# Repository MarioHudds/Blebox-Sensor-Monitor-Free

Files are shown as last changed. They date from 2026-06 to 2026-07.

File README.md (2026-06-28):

# 🌡️ Monitor Sensorów Blebox (ESP32-C3) / Blebox Sensor Monitor

*(Scroll down for the English version)*

Projekt garażowy open-source pozwalający na ciągłe wyświetlanie danych z czujników ekosystemu Blebox (tempSensor, humiditySensor, multiSensor) na klasycznym ekranie LCD 16x2 lub 24x4.

Zamiast polegać na chmurze producenta, urządzenie wykorzystuje architekturę hybrydową Bleboxa – komunikuje się z czujnikami całkowicie lokalnie, w obrębie domowej sieci Wi-Fi lub przez bezpośredni punkt dostępowy (AP) sensora, używając otwartego API po protokole HTTP (mechanizm pollingu).

## 🚀 Funkcje

* **Lokalne działanie:** Brak opóźnień chmurowych, odporność na awarie internetu.
* **Auto-wykrywanie mDNS:** Nie musisz znać adresu IP swojego sensora. Monitor sam znajdzie go w sieci po przyjaznej nazwie (`.local`).
* **Captive Portal:** Łatwa konfiguracja z poziomu przeglądarki w telefonie po pierwszym uruchomieniu.
* **Wsparcie dla sieci chronionych:** Możliwość łączenia się z zabezpieczonymi sieciami AP (Access Point) udostępnianymi przez czujniki.
* **Niezawodność:** Wbudowane mechanizmy ponawiania połączenia i obsługi błędów sieci (np. brak migotania ekranu przy chwilowej utracie sygnału).

## 🛠️ Wymagania sprzętowe (Pinout)

Projekt został zoptymalizowany dla mikrokontrolerów z rodziny **ESP32-C3** (np. SuperMini).

* **Wyświetlacz LCD 16x2 lub 24x4 dla odpowiedniego kodu (I2C, adres 0x27):**
  * `SDA` -> GPIO 10
  * `SCL` -> GPIO 20
* **Przycisk fizyczny (do nawigacji i resetu):**
  * `PIN` -> GPIO 4 (zwiera do GND, używa wbudowanego pull-up)
* **Dioda RGB (wyłączana programowo, by nie raziła):**
  * `DIN` -> GPIO 8 (wbudowana w płytkę SuperMini)

## 💻 Środowisko programistyczne i instalacja

**Ważne:** Oprogramowanie zostało stworzone i przetestowane w środowisku **Arduino IDE w wersji 2.3.6**. Ze względu na dynamiczny rozwój rdzenia ESP32 dla Arduino, używanie nowszych wersji kompilatora może wymagać drobnych korekt w kodzie lub downgrade'u bibliotek.

### Krok 1: Przygotowanie Arduino IDE

1. Dodaj wsparcie dla płytek ESP32 w *Preferencjach* (Adres URL menedżera dodatkowych płytek).
2. W Menedżerze Płytek zainstaluj pakiet `esp32` (autor: Espressif Systems).
3. Wybierz płytkę z menu: **ESP32C3 Dev Module** (lub odpowiednik dla Twojej płytki).

### Krok 2: Wymagane biblioteki

Otwórz Menedżera Bibliotek w Arduino IDE i upewnij się, że masz zainstalowane poniższe pozycje:

* `ArduinoJson` (autor: Benoit Blanchon) – do parsowania odpowiedzi HTTP
* `LiquidCrystal I2C` (autor: Frank de Brabander) – do obsługi ekranu
* `Adafruit NeoPixel` (autor: Adafruit) – do obsługi wbudowanej diody LED
* *Biblioteki wbudowane w rdzeń ESP32 (nie musisz ich doinstalowywać):* `WiFi`, `HTTPClient`, `Wire`, `EEPROM`, `DNSServer`, `WebServer`, `ESPmDNS`.

### Krok 3: Wgrywanie i bezpieczeństwo

Otwórz plik `.ino` i wgraj go na płytkę. **Uwaga dotycząca bezpieczeństwa:** Twoje hasła do Wi-Fi zapisywane są w wydzielonej partycji pamięci (EEPROM/Flash). Przed przekazaniem gotowego urządzenia komuś obcemu, zawsze wykonaj twardy reset (przytrzymanie przycisku przez >3 sekundy), aby wymazać swoje poufne dane dostępowe.

## ⚙️ Pierwsze uruchomienie

1. Po włączeniu na ekranie pojawi się informacja o trybie pracy.
2. Jeśli urządzenie nie jest skonfigurowane, uruchomi własną sieć Wi-Fi o nazwie **Monitor_TSHS**.
3. Połącz się z tą siecią ze swojego telefonu/komputera. Zostaniesz automatycznie przekierowany na stronę konfiguracyjną (jeśli nie, wpisz w przeglądarce `192.168.4.1`).
4. Wybierz z listy swoją sieć domową Wi-Fi i podaj hasło. Zapisz i poczekaj na restart urządzenia.

## 📄 Licencja

Projekt udostępniany na licencji **MIT**. Możesz modyfikować kod, używać go w projektach komercyjnych i dowolnie rozpowszechniać. Twórcy nie ponoszą odpowiedzialności za błędy wynikające z działania oprogramowania.

---

# 🇬🇧 English Version

An open-source, garage-developed standalone display for the Blebox ecosystem sensors (tempSensor, humiditySensor, multiSensor) using a classic 16x2 LCD.

Instead of relying on the manufacturer's cloud, this device uses Blebox's hybrid architecture – communicating with sensors entirely locally within your home Wi-Fi network or directly via the sensor's Access Point (AP). It fetches data using the open HTTP API (polling mechanism).

## 🚀 Features

* **Local Operation:** No cloud latency, immune to internet outages.
* **mDNS Auto-Discovery:** No need to hardcode IP addresses. The monitor finds the sensor via its `.local` hostname.
* **Captive Portal:** Easy mobile browser configuration on first boot.
* **Protected Network Support:** Ability to connect to secure APs provided by sensors.
* **Reliability:** Built-in reconnection mechanisms and network error handling (prevents screen flickering during temporary signal loss).

## 🛠️ Hardware Requirements (Pinout)

The project is optimized for the **ESP32-C3** family (e.g., SuperMini board).

* **16x2 LCD Display (I2C, address 0x27):**
  * `SDA` -> GPIO 10
  * `SCL` -> GPIO 20
* **Physical Button (navigation & reset):**
  * `PIN` -> GPIO 4 (shorts to GND, uses internal pull-up)
* **RGB LED (disabled via software):**
  * `DIN` -> GPIO 8 (built into the SuperMini board)

## 💻 Development Environment & Installation

**Important:** This software was developed and tested using **Arduino IDE version 2.3.6**. Due to the rapid development of the ESP32 Arduino core, compiling on newer versions might require minor code adjustments or library downgrades.

### Step 1: Arduino IDE Setup

1. Add ESP32 board support in *Preferences* (Additional Boards Manager URLs).
2. Install the `esp32` package by Espressif Systems via the Boards Manager.
3. Select your board: **ESP32C3 Dev Module** (or similar).

### Step 2: Required Libraries

Open the Library Manager and install:

* `ArduinoJson` (by Benoit Blanchon) – for parsing HTTP responses
* `LiquidCrystal I2C` (by Frank de Brabander) – for the display
* `Adafruit NeoPixel` (by Adafruit) – for onboard LED management
* *Core libraries (included with ESP32 core, no installation needed):* `WiFi`, `HTTPClient`, `Wire`, `EEPROM`, `DNSServer`, `WebServer`, `ESPmDNS`.

### Step 3: Flashing & Security Practices

Open the `.ino` file and flash it to your board. **Security Note:** Your Wi-Fi credentials are saved in the device's non-volatile memory (EEPROM/Flash). Before handing the physical device to someone else, always perform a hard reset (hold the button for >3 seconds) to erase your access data.

## ⚙️ Initial Setup

1. Upon power-up, the screen will display the current connection mode.
2. If unconfigured, it will broadcast a Wi-Fi network named **Monitor_TSHS**.
3. Connect to this network using your smartphone. You should be automatically redirected to the setup portal (if not, navigate to `192.168.4.1`).
4. Select your home Wi-Fi network, enter the password, save, and wait for the device to reboot.

## 📄 License

This project is licensed under the **MIT License**. You are free to modify, distribute, and use it in commercial applications. The authors are not liable for any issues arising from the use of this software.

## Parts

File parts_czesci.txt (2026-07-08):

## 🛒 Lista części (BOM) i przykładowe linki

Do złożenia Monitora w wersji 16x2 lub 20x4 i zamontowania go w obudowie 3D potrzebujesz poniższych części. Podane linki mają charakter wyłącznie poglądowy (mogą z czasem wygasnąć) – podczas zakupów kieruj się przede wszystkim nazwami i parametrami.
Części można kupić znacznie taniej niż są w poniższych linkach. Trzeba szukać ich na 'Bundle Deals' w Ali.

https://pl.aliexpress.com/item/1005006520514745.html

https://pl.aliexpress.com/item/1005009681060148.html

https://pl.aliexpress.com/item/1005009897797706.html

https://pl.aliexpress.com/item/1005008989080790.html

https://pl.aliexpress.com/item/1005006478143379.html

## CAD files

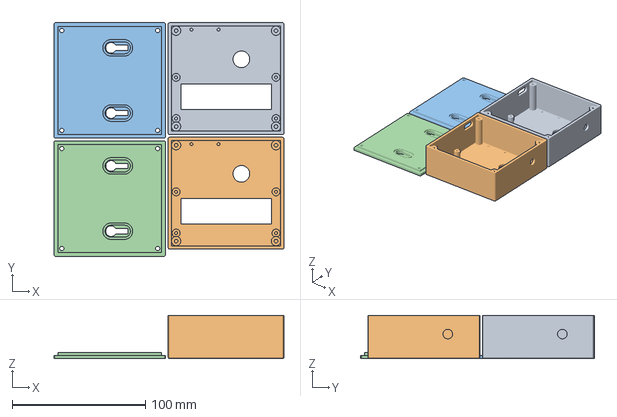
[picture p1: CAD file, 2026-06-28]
Enclosure_16x2_base_Lid_petgMatte_prod.3mf
172.7 x 175.4 x 32.5 mm
1602_enclosure_10072025_base_prod.stl x 2
1602_enclosure_base_Lid_84_prod.stl_2 x 2

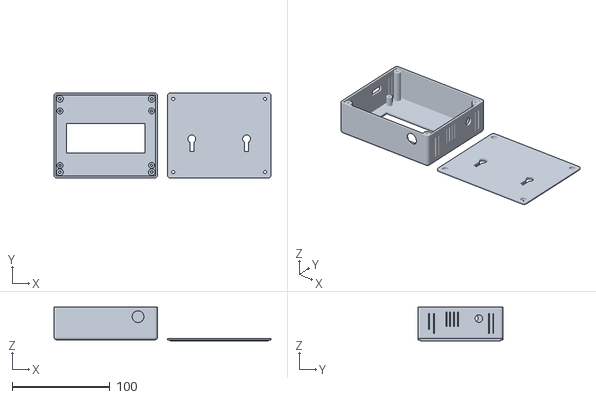
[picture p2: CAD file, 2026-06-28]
Enclosure_20x4_small_thinner_with_antenna_ventsGitHub.stl
222.0 x 87.0 x 34.5

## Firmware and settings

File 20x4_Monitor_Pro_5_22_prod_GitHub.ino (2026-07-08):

// ===================================================================================
//
//      ESP32-C3 PRO Project - Version 5.22 PL (Multi-Sensor FINAL)
//
// ===================================================================================
//
//v5.22 Fixed reconnection
//v5.21 Wind Unit in Carousel Mode & Unit is Not Saved
//v5.20 the password visibility fixed
//
// v5.17 Changelog:
//   - OPTIMIZE: Refactored display functions to use C-style strings (char arrays) 
//               instead of String objects to reduce heap fragmentation.
//   - OPTIMIZE: Modified HTTP fetching to parse JSON directly from the network stream,
//               avoiding large intermediate String allocations.
//
// v5.16 Changelog:
//   - FEATURE: Added manual/infinite carousel mode. Set interval to "Reczny" (Manual).
//
// v5.15 Changelog:
//   - REFACTOR: Created printHeaderLine() helper to centralize header/counter display.
//   - REFACTOR: Created handleFactoryReset() helper to centralize reset logic.
//
// v5.13 User Changes:
//   - FIX: Corrected carousel counter display (removed brackets, fixed positioning).
//   - FIX: Added reset functionality to the AP scanning menu.
//
// ===================================================================================
//
// -- Hardware & Pinout --
// Board: ESP32-C3 SuperMini / SuperMini Plus
// LCD Display (I2C):
//   - SDA: GPIO 10
//   - SCL: GPIO 20
// Button:
//   - PIN: GPIO 4
// Onboard RGB LED (WS2812):
//   - DIN: GPIO 8
//
// ===================================================================================

// --- Core Libraries ---
#include <WiFi.h>
#include <HTTPClient.h>
#include <Wire.h>
#include <ArduinoJson.h>
#include <LiquidCrystal_I2C.h>
#include <EEPROM.h>

// --- New Libraries for WiFi Mode & LED ---
#include <DNSServer.h>
#include <WebServer.h>
#include <ESPmDNS.h>
#include <Adafruit_NeoPixel.h>

// --- Configuration ---
#define NEOPIXEL_PIN 8
#define NUM_PIXELS   1
Adafruit_NeoPixel strip(NUM_PIXELS, NEOPIXEL_PIN, NEO_GRB + NEO_KHZ800);

// --- User Configuration Flag ---
#define WIND_UNIT_MODE 0
#define MAX_SENSORS 5    // Maximum number of sensors to support

const int I2C_ADDR = 0x27;
const int SDA_PIN = 10;
const int SCL_PIN = 20;
const int LCD_COLS = 20;
const int LCD_ROWS = 4;
LiquidCrystal_I2C lcd(I2C_ADDR, LCD_COLS, LCD_ROWS);

const int BUTTON_PIN = 4;
const char* CAPTIVE_PORTAL_SSID = "Monitor_PRO";
const char* MONITOR_HOSTNAME = "monitor";
WebServer webServer(80);
DNSServer dnsServer;

enum SensorType { SENSOR_UNKNOWN, SENSOR_TEMP, SENSOR_HUMIDITY, SENSOR_WIND, SENSOR_MULTI_TEMP };
enum WindUnit { UNIT_MS, UNIT_KMH, UNIT_MPH, UNIT_KNOTS };
enum ConnectionMode { MODE_UNSET = 0, MODE_AP = 1, MODE_WIFI = 2, MODE_AP_SECURE_SETUP = 3 };

// --- EEPROM Configuration (v5.00) ---
struct SensorInfo {
  char mDNSSensorName[65];         // e.g., "czujnik-garaz.local". Empty if manual IP.
  char mDNSSensorFriendlyName[33]; // e.g., "Czujnik Garaz"
  char sensorIp[16];               // Can be a manual IP or a cached IP from mDNS.
};

struct Settings {
  int connectionMode;
  char wifiSSID[33];
  char wifiPassword[65];

  // --- Single AP Mode Settings ---
  char apModeSsid[33];
  bool connectToProtectedAP;
  char protectedApSsid[33];
  char protectedApPassword[65];

  // --- Multi-sensor WiFi Mode Settings ---
  int sensorCount;
  SensorInfo selectedSensors[MAX_SENSORS];
  int carouselInterval; // in seconds

  WindUnit windUnit; // Add a variable to store the preferred wind unit
};

const int EEPROM_ADDR = 0;
const int EEPROM_SIZE = sizeof(Settings) + 1;
Settings settings;




bool firstWifiRun = true;
int buttonState = HIGH;
int lastButtonState = HIGH;
unsigned long lastDebounceTime = 0;
unsigned long buttonPressStartTime = 0;
WindUnit currentWindUnit = UNIT_MS;

const int MAX_FOUND_APS = 10;
String foundAP_SSIDs[MAX_FOUND_APS];
String foundAP_DisplayNames[MAX_FOUND_APS];
int foundAPCount = 0;
const int MAX_MDNS_SERVICES = 20;
String foundMDNS_Names[MAX_MDNS_SERVICES];
String foundMDNS_Hostnames[MAX_MDNS_SERVICES];
int foundMDNSCount = 0;
String selectedSensorHostname = ""; // Legacy, will be phased out.
String baseApiUrl = "";
SensorType connectedSensorApiType = SENSOR_UNKNOWN;
unsigned long lastDataFetchTime = 0; // Re-purposed for carousel timer

const char* DATA_ENDPOINT_PATH = "/state/extended";
const char* INFO_ENDPOINT_PATH = "/info";

int currentSensorIndex = 0;
IPAddress sensorIPs[MAX_SENSORS]; // Session cache for resolved IP addresses

const char* TEMP_AP_PREFIX_1 = "tempSensor-";
const char* TEMP_AP_PREFIX_2 = "tempSensor_v2-";
const char* TEMP_AC_AP_PREFIX = "tempSensorAC-";
const char* TEMP_AC_V2_AP_PREFIX = "tempSensorAC_v2-";
const char* TEMP_PRO_AP_PREFIX = "tempSensorPRO-";
const char* TEMP_PRO_UNDERSCORE_AP_PREFIX = "tempSensor_PRO-";
const char* TEMP_PRO_V2_AP_PREFIX = "tempSensor_PRO_v2-";
const char* TEMP_DIN_AP_PREFIX = "tempSensor_DIN-";
const char* HUMIDITY_AP_PREFIX = "humiditySensor-";
const char* HUMIDITY_AP_PREFIX_V2 = "humiditySensor_v2-"; // NEW (v5.12)
const char* WIND_AP_PREFIX = "windSensor_PRO-";
const char* WIND_RAIN_AP_PREFIX = "windRainSensor-";

const int NO_PRESS = 0;
const int SHORT_PRESS_DETECTED = 1;
const int LONG_PRESS_DETECTED = 2;
const int VERY_LONG_PRESS_DETECTED = 3;
const unsigned long DEBOUNCE_DELAY = 50;
const unsigned long SHORT_PRESS_MAX_DURATION = 1000;
const unsigned long LONG_PRESS_MIN_DURATION = 3000;
const unsigned long VERY_LONG_PRESS_MIN_DURATION = 7000;

byte degreeSymbol[8] = { 0b00110, 0b01001, 0b01001, 0b00110, 0b00000, 0b00000, 0b00000, 0b00000 };
byte upArrow[8] = { 0B00100, 0B01110, 0B11111, 0B00100, 0B00100, 0B00000, 0B00000, 0B00000 };
byte downArrow[8] = { 0B00000, 0B00000, 0B00100, 0B00100, 0B11111, 0B01110, 0B00100, 0B00000 };
byte rssiGraphic1[8] = { 0b00000, 0b00000, 0b00000, 0b00000, 0b00000, 0b00000, 0b10000, 0b10000 };
byte rssiGraphic2[8] = { 0b00000, 0b00000, 0b00000, 0b00000, 0b01000, 0b01000, 0b11000, 0b11000 };
byte rssiGraphic3[8] = { 0b00000, 0b00000, 0b00100, 0b00100, 0b01100, 0b01100, 0b11100, 0b11100 };
byte rssiGraphic4[8] = { 0b00010, 0b00010, 0b00110, 0b00110, 0b01110, 0b01110, 0b11110, 0b11110 };
byte waterDrop[8] = { 0b00100, 0b00100, 0b01010, 0b01010, 0b11001, 0b11001, 0b11101, 0b01110 };
const byte DEGREE_CHAR_INDEX = 0, UP_ARROW_CHAR_INDEX = 1, DOWN_ARROW_CHAR_INDEX = 2, RSSI_GRAPHIC_1_INDEX = 3, RSSI_GRAPHIC_2_INDEX = 4, RSSI_GRAPHIC_3_INDEX = 5, RSSI_GRAPHIC_4_INDEX = 6, WATER_DROP_CHAR_INDEX = 7;

struct SensorReading {
  int tempProbeCount;
  float temperatures[4];
  int tempTrends[4];
  String probeNames[4];
  bool tempSuccess;
  float humidity;
  int humidityTrend;
  bool humiditySuccess;
  float windSpeed;
  float windAvg;
  float windMax;
  bool windSuccess;
};

struct DeviceInfo {
  String deviceName;
  String apiType;
  String product;
  bool success;
};

// --- State Tracking Variables ---
DeviceInfo lastGoodDeviceInfo;
SensorReading lastGoodSensorData;
long lastGoodRSSI = -100;
bool hasDataToDisplay = false;
String lastDisplayedName = "";
// --- REFACTOR START: Replaced String arrays with char arrays ---
#define MAX_VALUE_LEN 11        // Max length for a displayed value string (e.g., "-123.45\0")
#define MAX_PROBE_NAME_LEN 11   // Max length for a probe name (display truncates to 10)
char lastDisplayedValues[4][MAX_VALUE_LEN] = {"", "", "", ""};
char lastDisplayedProbeNames[4][MAX_PROBE_NAME_LEN] = {"", "", "", ""};
// --- REFACTOR END ---
int lastDisplayedTrends[4] = {-1, -1, -1, -1};
long lastDisplayedRSSI = -200;
SensorType lastDisplayedType = SENSOR_UNKNOWN;
WindUnit lastWindUnit = UNIT_MS;
int consecutiveFetchFailures = 0;
const int MAX_CONSECUTIVE_FETCH_FAILURES = 3;
int lastProbeCount = -1;

// --- Function Declarations ---
void loadSettings(); void saveSettings(); void eraseSettings(); void setup(); void loop(); int checkButton();
void handleDataFetching();
ConnectionMode selectConnectionMode();
void startCaptivePortal(); void handleWifiConfigRoot(); void handleWifiConfigSave();
void handleNotFound();
void handleSettingsMenu();
bool discoverAndSelectMDNS_Sensor();
bool scanAndSelectAP(); bool connectToAP(const String& ssid, const char* password = nullptr);
DeviceInfo fetchDeviceInfo(const String& endpoint); SensorReading fetchSensorData(const String& endpoint, SensorType type);
void displayTemp(const DeviceInfo& info, const SensorReading& data, long rssi);
void displayHumidity(const DeviceInfo& info, const SensorReading& data, long rssi);
void displayWind(const DeviceInfo& info, const SensorReading& data, long rssi);
void displayMultiTemp(const DeviceInfo& info, const SensorReading& data, long rssi);
// --- NEW HELPER FUNCTIONS ---
void handleFactoryReset();
void printHeaderLine(const String& deviceName);

// ===================================================================================
//                                  SETUP
// ===================================================================================
void setup() {
  // Serial.begin(115200);
  pinMode(BUTTON_PIN, INPUT_PULLUP);

  strip.begin();
  strip.clear();
  strip.setPixelColor(0, strip.Color(0, 0, 0));
  strip.show();

  delay(500);

  Wire.begin(SDA_PIN, SCL_PIN);
  lcd.init();
  lcd.backlight();
  lcd.clear();
  delay(50);
  lcd.createChar(DEGREE_CHAR_INDEX, degreeSymbol);
  lcd.createChar(UP_ARROW_CHAR_INDEX, upArrow);
  lcd.createChar(DOWN_ARROW_CHAR_INDEX, downArrow);
  lcd.createChar(RSSI_GRAPHIC_1_INDEX, rssiGraphic1);
  lcd.createChar(RSSI_GRAPHIC_2_INDEX, rssiGraphic2);
  lcd.createChar(RSSI_GRAPHIC_3_INDEX, rssiGraphic3);
  lcd.createChar(RSSI_GRAPHIC_4_INDEX, rssiGraphic4);
  lcd.createChar(WATER_DROP_CHAR_INDEX, waterDrop);

  EEPROM.begin(EEPROM_SIZE);
  loadSettings();

  bool setupOk = false;
  if (settings.connectToProtectedAP) {
      lcd.clear();
      lcd.print("Laczenie z...");
      lcd.setCursor(0,1);
      lcd.print(settings.protectedApSsid);
      while(!connectToAP(settings.protectedApSsid, settings.protectedApPassword)) {
          lcd.clear();
          lcd.print("Szukam AP...");
          lcd.setCursor(0,1);
          lcd.print(String(settings.protectedApSsid).substring(0,20));
          delay(2000);
      }
      settings.connectionMode = MODE_AP;
      setupOk = true;
  } else {
    if (settings.connectionMode == MODE_UNSET) {
      settings.connectionMode = selectConnectionMode();
      if (settings.connectionMode == MODE_AP_SECURE_SETUP || (settings.connectionMode == MODE_WIFI && strlen(settings.wifiSSID) == 0)) {
          startCaptivePortal();
      }
      saveSettings();
    }
  }

  if (settings.connectionMode == MODE_AP) {
    if (strlen(settings.apModeSsid) > 0) {
        lcd.clear();
        lcd.print("Laczenie z...");
        lcd.setCursor(0,1);
        lcd.print(settings.apModeSsid);
        while(!connectToAP(settings.apModeSsid)) {
            lcd.clear();
            lcd.print("Szukam AP...");
            lcd.setCursor(0,1);
            lcd.print(String(settings.apModeSsid).substring(0,20));
            delay(2000);
        }
        setupOk = true;
    } else if (!settings.connectToProtectedAP) {
        setupOk = scanAndSelectAP();
    } else {
        setupOk = true;
    }

  } else if (settings.connectionMode == MODE_WIFI) {
    if (strlen(settings.wifiSSID) == 0) {
      startCaptivePortal();
    }

    lcd.clear();
    lcd.print("Tryb WiFi");
    delay(1500);
    lcd.clear();
    lcd.print("Laczenie z WiFi");
    lcd.setCursor(0, 1);
    lcd.print(settings.wifiSSID);

    WiFi.begin(settings.wifiSSID, settings.wifiPassword);
    unsigned long startTime = millis();
    while (WiFi.status() != WL_CONNECTED) {
      int press = checkButton();
      if (press == VERY_LONG_PRESS_DETECTED) {
        // REPLACED WITH HELPER
        handleFactoryReset();
      }

      delay(250);
      lcd.print(".");
      // --- BUGFIX START: Do not erase settings on connection timeout ---
      // If 20 seconds pass and we're not connected, show an error and break
      // the loop instead of erasing the configuration. The main loop will
      // handle reconnection attempts.
      if (millis() - startTime > 20000) {
        lcd.clear();
        lcd.print("Blad polaczenia");
        lcd.setCursor(0, 1);
        lcd.print("Sprawdz ruter/AP");
        lcd.setCursor(0, 2);
        lcd.print("Sprobuje ponownie...");
        delay(4000);
        // eraseSettings(); // OLD DESTRUCTIVE BEHAVIOR - REMOVED
        // ESP.restart();   // OLD DESTRUCTIVE BEHAVIOR - REMOVED
        break; // Exit the connection loop and proceed to the main program
      }
      // --- BUGFIX END ---
    }

      // Only attempt mDNS setup or sensor discovery if we successfully connected.
    if (WiFi.status() == WL_CONNECTED) {
        if (!MDNS.begin(MONITOR_HOSTNAME)) {
            lcd.clear();
            lcd.print("Blad mDNS");
            delay(3000);
            // We don't restart, just note the error.
        }

        if (settings.sensorCount == 0) {
          setupOk = discoverAndSelectMDNS_Sensor();
        } else {
          setupOk = true;
        }
    } else {
        // If WiFi failed to connect, we still consider setup "ok" to allow
        // the main loop's reconnection logic to take over.
        setupOk = true;
    }
  }

  if (!setupOk) {
    lcd.clear();
    lcd.print("Blad konfiguracji");
    lcd.setCursor(0, 1);
    lcd.print("Restartuje...");
    delay(3000);
    eraseSettings();
    ESP.restart();
  }

  for(int i = 0; i < settings.sensorCount; i++) {
    sensorIPs[i].fromString(settings.selectedSensors[i].sensorIp);
  }

  lcd.clear();
  lcd.print("Gotowe");
  lastDataFetchTime = millis();
  delay(1000);
  handleDataFetching();
}


// ===================================================================================
//                                  MAIN LOOP
// ===================================================================================

void loop() {
  int press = checkButton();

  if (press == VERY_LONG_PRESS_DETECTED) {
    handleFactoryReset();
  } else if (press == LONG_PRESS_DETECTED) {
      if(settings.connectionMode == MODE_WIFI && settings.sensorCount > 1) {
        handleSettingsMenu();
        lastDataFetchTime = millis();

        lastDisplayedName = "";
        connectedSensorApiType = SENSOR_UNKNOWN;

        handleDataFetching();
      }
  } else if (press == SHORT_PRESS_DETECTED) {
    bool carouselAdvanced = false;
    if (settings.connectionMode == MODE_WIFI && settings.sensorCount > 1) {
        currentSensorIndex = (currentSensorIndex + 1) % settings.sensorCount;
        lastDataFetchTime = millis();

        lastDisplayedName = "";
        connectedSensorApiType = SENSOR_UNKNOWN;

        handleDataFetching();
        carouselAdvanced = true;
    }

    if (!carouselAdvanced && connectedSensorApiType == SENSOR_WIND) {
      if (WIND_UNIT_MODE == 0) {
          currentWindUnit = (currentWindUnit == UNIT_MS) ? UNIT_KMH : UNIT_MS;
      } else {
          currentWindUnit = (WindUnit)((currentWindUnit + 1) % 4);
      }

      // --- NEW: Persist the user's selection to EEPROM ---
      settings.windUnit = currentWindUnit;
      saveSettings();
      // --- END NEW ---

      lastDisplayedName = "";
      if(hasDataToDisplay) displayWind(lastGoodDeviceInfo, lastGoodSensorData, lastGoodRSSI);
    }
  }

  // --- BUGFIX START: Corrected data fetching logic for manual carousel mode ---

  // Case 1: Automatic Carousel is active.
  // This block handles both advancing the sensor AND fetching data on a user-defined timer.
  if (settings.connectionMode == MODE_WIFI && settings.sensorCount > 1 && settings.carouselInterval > 0) {
    if (millis() - lastDataFetchTime >= ((unsigned long)settings.carouselInterval * 1000)) {
        currentSensorIndex = (currentSensorIndex + 1) % settings.sensorCount;
        lastDataFetchTime = millis();

        lastDisplayedName = "";
        connectedSensorApiType = SENSOR_UNKNOWN;

        handleDataFetching();
    }
  }
  // Case 2: All other modes (AP, single sensor, or MANUAL carousel).
  // This block handles fetching data for the CURRENT sensor on a fixed 3-second timer.
  else if (settings.connectionMode == MODE_AP || (settings.connectionMode == MODE_WIFI && settings.sensorCount >= 1)) {
    if (millis() - lastDataFetchTime >= 3000) {
      lastDataFetchTime = millis();
      handleDataFetching();
    }
  }
  // --- BUGFIX END ---
}

// ===================================================================================
//                        NETWORK & DATA HANDLING FUNCTION
// ===================================================================================
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

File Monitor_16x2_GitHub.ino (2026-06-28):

// ===================================================================================
//
//      ESP32-C3 TSHS Project - Version 3.44 PL (Upgraded)
//
// ===================================================================================
//
// v3.44 Changelog:
//   - FIX (Protected AP Mode): The monitor no longer resets if the saved protected
//     sensor AP is unavailable on startup. It now uses the same persistent
//     reconnection logic as the standard AP mode.
//
// v3.43 Changelog:
//   - FIX (AP Mode): The monitor no longer resets its settings if the saved sensor
//     AP is unavailable on startup. It will now persistently try to reconnect
//     until successful, while still allowing for a manual reset via long press.
//
// v3.42 Changelog:
//   - FIX: Implemented a visual indicator for sensor connection loss.
//   - UX: When the sensor is disconnected, the monitor now displays "Utracono sygnal"
//     (Signal lost) instead of showing stale data, while continuing to attempt
//     reconnection in the background.
//
// ===================================================================================
//
// -- Hardware & Pinout --
// Board: ESP32-C3 SuperMini / SuperMini Plus
// LCD Display (I2C): 16x2
//   - SDA: GPIO 10
//   - SCL: GPIO 20
// Button:
//   - PIN: GPIO 4
// Onboard RGB LED (WS2812):
//   - DIN: GPIO 8
//
// ===================================================================================


// --- Core Libraries ---
// [EDUKACJA]: Podstawowe biblioteki do obsługi sieci, zapytań HTTP i interfejsów sprzętowych.
#include <WiFi.h>
#include <HTTPClient.h>
#include <Wire.h>               // Obsługa magistrali I2C (dla wyświetlacza)
#include <ArduinoJson.h>        // Parsowanie odpowiedzi z sensorów Blebox (które zwracają dane w formacie JSON)
#include <LiquidCrystal_I2C.h>  // Sterowanie ekranem LCD
#include <EEPROM.h>             // Zapisywanie ustawień w pamięci nieulotnej (flash)

// --- New Libraries for WiFi Mode & LED ---
// [EDUKACJA]: Biblioteki do zaawansowanych funkcji sieciowych.
#include <DNSServer.h>          // Przechwytywanie zapytań DNS (niezbędne do działania "Captive Portal")
#include <WebServer.h>          // Wbudowany miniserwer WWW do konfiguracji przez przeglądarkę
#include <ESPmDNS.h>            // Multicast DNS: pozwala szukać urządzeń po nazwach (np. sensor.local) bez znajomości ich IP
#include <Adafruit_NeoPixel.h>

// --- Configuration ---
#define NEOPIXEL_PIN 8
#define NUM_PIXELS   1
Adafruit_NeoPixel strip(NUM_PIXELS, NEOPIXEL_PIN, NEO_GRB + NEO_KHZ800);

const int I2C_ADDR = 0x27; // [EDUKACJA]: Najpopularniejszy adres I2C dla tanich modułów LCD. Jeśli masz krzaczki na ekranie, sprawdź 0x3F.
const int SDA_PIN = 10;
const int SCL_PIN = 20;
LiquidCrystal_I2C lcd(I2C_ADDR, 16, 2);

const int BUTTON_PIN = 4;
const char* CAPTIVE_PORTAL_SSID = "Monitor_TSHS";
const char* MONITOR_HOSTNAME = "monitor";
WebServer webServer(80); // [EDUKACJA]: Serwer nasłuchuje na standardowym porcie HTTP (80)
DNSServer dnsServer;

// --- EEPROM Configuration ---
// [EDUKACJA][BEZPIECZEŃSTWO]: Ta struktura przechowuje dane konfiguracyjne. 
// Uwaga dla zaawansowanych: hasła (wifiPassword) są tutaj zapisywane jawnym tekstem. 
// Przy fizycznym dostępie do układu ESP32 można je odczytać. W projektach domowych to akceptowalne ryzyko.
struct Settings {
  int connectionMode;
  char wifiSSID[33];
  char wifiPassword[65];
  char mDNSSensorName[65];
  char mDNSSensorFriendlyName[33];
  char apModeSsid[33];

// New fields for protected AP mode
  bool connectToProtectedAP;
  char protectedApSsid[33];
  char protectedApPassword[65];
};
const int EEPROM_ADDR = 0;

const int EEPROM_SIZE = sizeof(Settings) + 1; // [EDUKACJA]: Rezerwujemy dokładnie tyle bajtów, ile waży nasza struktura
Settings settings;

// --- Enums, Globals, Constants, Structs... ---
enum ConnectionMode { MODE_UNSET = 0, MODE_AP = 1, MODE_WIFI = 2, MODE_AP_SECURE_SETUP = 3 };

bool firstWifiRun = true;
int buttonState = HIGH;
int lastButtonState = HIGH;
unsigned long lastDebounceTime = 0;

unsigned long buttonPressStartTime = 0;
bool longPressTriggered = false;
const int MAX_FOUND_APS = 10;
String foundAP_SSIDs[MAX_FOUND_APS];
String foundAP_DisplayNames[MAX_FOUND_APS];

int foundAPCount = 0;
const int MAX_MDNS_SERVICES = 10;
String foundMDNS_Names[MAX_MDNS_SERVICES];
String foundMDNS_Hostnames[MAX_MDNS_SERVICES];
int foundMDNSCount = 0;

String selectedSensorHostname = "";
String baseApiUrl = "";
IPAddress sensorIP;

// Variable to cache the sensor's IP address
String connectedSensorType = "";
unsigned long lastDataFetchTime = 0;

// [EDUKACJA]: Interwał odpytywania (polling) ustawiony na 5000 ms (5 sekund). 
// Sensory Blebox nie potrafią same "wypchnąć" (push) informacji o każdej drobnej zmianie temperatury 
// bez skomplikowanej konfiguracji dziesiątek akcji. Dlatego nasz monitor regularnie odpytuje sensor o stan.
const unsigned long DATA_FETCH_INTERVAL = 5000; 

const char* TEMP_ENDPOINT_PATH = "/state";
const char* INFO_ENDPOINT_PATH = "/info";

//Wykrywane czujniki

const char* TEMP_AP_PREFIX_1 = "tempSensor-";
const char* TEMP_AP_PREFIX_2 = "tempSensor_v2-";
const char* HUMIDITY_AP_PREFIX = "humiditySensor-";
const int NO_PRESS = 0;

const int SHORT_PRESS_DETECTED = 1;
const int LONG_PRESS_DETECTED = 2;
const unsigned long DEBOUNCE_DELAY = 50; // [EDUKACJA]: Eliminacja drgań styków przycisku sprzętowego

const unsigned long SHORT_PRESS_MAX_DURATION = 1000; // Krótkie kliknięcie (do 1 sekundy)
const unsigned long LONG_PRESS_MIN_DURATION = 3000;  // Długie kliknięcie (powyżej 3 sekund, np. do resetu)

// [EDUKACJA]: Definicje własnych znaków (piksel po pikselu) dla ekranu HD44780
byte degreeSymbol[8] = { B00110, B01001, B01001, B00110, B00000, B00000, B00000, B00000 };
byte upArrow[8] = { B00100, B01110, B11111, B00100, B00100, B00000, B00000, B00000 };
byte downArrow[8] = { B00000, B00000, B00100, B00100, B11111, B01110, B00100, B00000 };
byte rssiGraphic1[8] = { B00000, B00000, B00000, B00000, B00000, B00000, B10000, B10000 };
byte rssiGraphic2[8] = { B00000, B00000, B00000, B00000, B01000, B01000, B11000, B11000 };
byte rssiGraphic3[8] = { B00000, B00000, B00100, B00100, B01100, B01100, B11100, B11100 };
byte rssiGraphic4[8] = { B00010, B00010, B00110, B00110, B01110, B01110, B11110, B11110 };
byte waterDrop[8] = { B00100, B00100, B01010, B01010, B11001, B11001, B11101, B01110 };

const byte DEGREE_CHAR_INDEX = 0, UP_ARROW_CHAR_INDEX = 1, DOWN_ARROW_CHAR_INDEX = 2, RSSI_GRAPHIC_1_INDEX = 3, RSSI_GRAPHIC_2_INDEX = 4, RSSI_GRAPHIC_3_INDEX = 5, RSSI_GRAPHIC_4_INDEX = 6, WATER_DROP_CHAR_INDEX = 7;

// [EDUKACJA]: Struktury grupujące powiązane ze sobą dane dla porządku w kodzie
struct SensorReading { float temperature; int tempTrend; bool tempSuccess; float humidity; int humidityTrend; bool humiditySuccess; };
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

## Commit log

2026-06-28 Change LCD display size to both 16x2 and 24x3
    Updated the display specifications for the Blebox sensor monitor project.
2026-06-28 Add sensor prefix constants for temperature and humidity
2026-06-28 Update BOM list with additional purchasing advice
    Added a note about finding cheaper parts on 'Bundle Deals' in AliExpress.
2026-07-08 Revise BOM list for monitor assembly
    Updated the BOM list for the monitor assembly to reflect the correct version and links.
